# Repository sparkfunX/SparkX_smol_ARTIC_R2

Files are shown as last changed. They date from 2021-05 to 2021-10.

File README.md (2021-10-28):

# SparkX smôl ARTIC R2

SparkX smôl ARTIC R2 (SPX-18618) (https://www.sparkfun.com/products/18618)

[*SparkX smôl ARTIC R2 (SPX-18618)*](https://www.sparkfun.com/products/18618)

The ARGOS ARTIC R2 satellite communication chipset in smôl format.

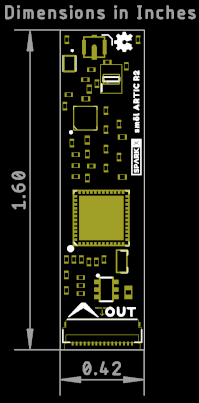
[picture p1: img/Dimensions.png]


## Repository Contents

- [**/Hardware**](./Hardware) - Eagle PCB, SCH and LBR design files
- [**LICENSE.md**](./LICENSE.md) - contains the licence information

## Product Versions

- [SPX-18618](https://www.sparkfun.com/products/18618) - Original SparkX Release.

## Thanks

The ARTIC R2 circuit is a remix of the reference design kindly provided by the [Arribada Initiative](https://arribada.org/) and Icoteq Ltd.

## License Information

This product is _**open source**_!

Please review the LICENSE.md file for license information.

If you have any questions or concerns on licensing, please contact technical support on our [SparkFun forums](https://forum.sparkfun.com/viewforum.php?f=123).

Distributed as-is; no warranty is given.

- Your friends at SparkFun.

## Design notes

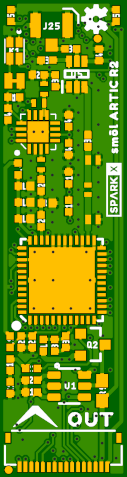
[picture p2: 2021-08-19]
img/Top.png

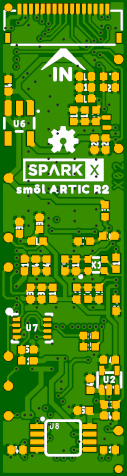
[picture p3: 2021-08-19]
img/Bottom.png

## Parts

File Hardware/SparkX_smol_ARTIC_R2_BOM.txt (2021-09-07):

Partlist exported from C:/Users/pc235/Documents/EAGLE/SparkX_smol_ARTIC_R2/X02/SparkX_smol_ARTIC_R2.sch at 07/09/2021 13:14

Part      Value                         Device                          Package                       Description                                                                                                     DESCRIPTION                                               DESIGNER DIGIKEY_PART                             MANUFACTURER_NAME MANUFACTURER_PART_NUMBER MANU_PART                MOUSER_PART          MOUSER_PART_NUMBER PACKAGE   PROD_ID     REV VALUE        
1V8       TEST-POINT3                   TEST-POINT3                     PAD.03X.03                    SparkFun Test Points                                                                                                                                                                                                                                                                                                                                                           
3V0       TEST-POINT3                   TEST-POINT3                     PAD.03X.03                    SparkFun Test Points                                                                                                                                                                                                                                                                                                                                                           
C1        2.2uF                         2.2UF-0402_TIGHT-10V-10%-X5R    0402-TIGHT                    2.2µF ceramic capacitors                                                                                                                                                                                                                                                                                                                          CAP-14232       2.2uF        
C2        10nF                          10NF-0402T-25V-10%              0402-TIGHT                    0.01uF/10nF/10,000pF ceramic capacitors                                                                                                                                                                                                                                                                                                           CAP-14847       10nF         
C3        1.0uF                         1.0UF-0402T-16V-10%             0402-TIGHT                    1µF ceramic capacitors                                                                                                                                                                                                                                                                                                                            CAP-12417       1.0uF        
C4        1.0uF                         1.0UF-0402T-16V-10%             0402-TIGHT                    1µF ceramic capacitors                                                                                                                                                                                                                                                                                                                            CAP-12417       1.0uF        
C5        22pF                          22PF-0402T-16V-10%              0402-TIGHT                    22pF ceramic capacitors                                                                                                                                                                                                                                                                                                                           CAP-14674       22pF         
C6        0.1uF                         0.1UF-0402T-6.3V-10%-X7R        0402-TIGHT                    0.1µF ceramic capacitors                                                                                                                                                                                                                                                                                                                          CAP-14993       0.1uF        
C7        22pF                          22PF-0402T-16V-10%              0402-TIGHT                    22pF ceramic capacitors                                                                                                                                                                                                                                                                                                                           CAP-14674       22pF         
C8        0.1uF                         0.1UF-0402T-6.3V-10%-X7R        0402-TIGHT                    0.1µF ceramic capacitors                                                                                                                                                                                                                                                                                                                          CAP-14993       0.1uF        
C9        1.0uF                         1.0UF-0402T-16V-10%             0402-TIGHT                    1µF ceramic capacitors                                                                                                                                                                                                                                                                                                                            CAP-12417       1.0uF        
C10       47nF                          47NF-0402_TIGHT-25V-10%-X7R     0402-TIGHT                    47nF ceramic capacitors                                                                                                                                                                                                                                                                                                                           CAP-14243       47nF         
C11       100pF                         100PF-0402T-50V-5%              0402-TIGHT                    100pF/0.1nF ceramic capacitors                                                                                                                                                                                                                                                                                                                    CAP-13458       100pF        
C12       1.0uF                         1.0UF-0402T-16V-10%             0402-TIGHT                    1µF ceramic capacitors                                                                                                                                                                                                                                                                                                                            CAP-12417       1.0uF        
C13       10uF                          10UF-0402T-6.3V-20%             0402-TIGHT                    10.0µF ceramic capacitors                                                                                                                                                                                                                                                                                                                         CAP-14848       10uF         
C14       10uF                          10UF-0402T-6.3V-20%             0402-TIGHT                    10.0µF ceramic capacitors                                                                                                                                                                                                                                                                                                                         CAP-14848       10uF         
C15       2.2uF                         2.2UF-0402_TIGHT-10V-10%-X5R    0402-TIGHT                    2.2µF ceramic capacitors                                                                                                                                                                                                                                                                                                                          CAP-14232       2.2uF        
C16       2.2uF                         2.2UF-0402_TIGHT-10V-10%-X5R    0402-TIGHT                    2.2µF ceramic capacitors                                                                                                                                                                                                                                                                                                                          CAP-14232       2.2uF        
C17       1.0nF                         1.0NF/1000PF-0402_TIGHT-50V-10% 0402-TIGHT                    1nF/1,000pF ceramic capacitors                                                                                                                                                                                                                                                                                                                    CAP-14280       1.0nF        
C18       22pF                          22PF-0402T-16V-10%              0402-TIGHT                    22pF ceramic capacitors                                                                                                                                                                                                                                                                                                                           CAP-14674       22pF         
C19       100pF                         100PF-0402T-50V-5%              0402-TIGHT                    100pF/0.1nF ceramic capacitors                                                                                                                                                                                                                                                                                                                    CAP-13458       100pF        
C20       2.2uF                         2.2UF-0402_TIGHT-10V-10%-X5R    0402-TIGHT                    2.2µF ceramic capacitors                                                                                                                                                                                                                                                                                                                          CAP-14232       2.2uF        
C21       100pF                         100PF-0402T-50V-5%              0402-TIGHT                    100pF/0.1nF ceramic capacitors                                                                                                                                                                                                                                                                                                                    CAP-13458       100pF        
C22       100pF                         100PF-0402T-50V-5%              0402-TIGHT                    100pF/0.1nF ceramic capacitors                                                                                                                                                                                                                                                                                                                    CAP-13458       100pF        
C23       1.0uF                         1.0UF-0402T-16V-10%             0402-TIGHT                    1µF ceramic capacitors                                                                                                                                                                                                                                                                                                                            CAP-12417       1.0uF        
C24       100pF                         100PF-0402T-50V-5%              0402-TIGHT                    100pF/0.1nF ceramic capacitors                                                                                                                                                                                                                                                                                                                    CAP-13458       100pF        
C25       100pF                         100PF-0402T-50V-5%              0402-TIGHT                    100pF/0.1nF ceramic capacitors                                                                                                                                                                                                                                                                                                                    CAP-13458       100pF        
C26       0.1uF                         0.1UF-0402T-6.3V-10%-X7R        0402-TIGHT                    0.1µF ceramic capacitors                                                                                                                                                                                                                                                                                                                          CAP-14993       0.1uF        
C27       22pF                          22PF-0402T-16V-10%              0402-TIGHT                    22pF ceramic capacitors                                                                                                                                                                                                                                                                                                                           CAP-14674       22pF         
C28       9.1pF                         9.1PF-0402-TIGHT                0402-TIGHT                    9.1pF ceramic capacitors                                                                                                                                                                                                                                                                        609-500R07S9R1CV4T                                CAP-15278       9.1pF        
C29       2.4 pF                        2.4PF-0402                      0402_MURATA                                                                                                                                                                                                                                                                                                                                                                     CAP-14351       2.4 pF       
C30       100pF                         100PF-0402T-50V-5%              0402-TIGHT                    100pF/0.1nF ceramic capacitors                                                                                                                                                                                                                                                                                                                    CAP-13458       100pF        
C31       100pF                         100PF-0402T-50V-5%              0402-TIGHT                    100pF/0.1nF ceramic capacitors                                                                                                                                                                                                                                                                                                                    CAP-13458       100pF        
C32       0.1uF                         0.1UF-0402T-6.3V-10%-X7R        0402-TIGHT                    0.1µF ceramic capacitors                                                                                                                                                                                                                                                                                                                          CAP-14993       0.1uF        
C33       22pF                          22PF-0402T-16V-10%              0402-TIGHT                    22pF ceramic capacitors                                                                                                                                                                                                                                                                                                                           CAP-14674       22pF         
C34       22pF                          22PF-0402T-16V-10%              0402-TIGHT                    22pF ceramic capacitors                                                                                                                                                                                                                                                                                                                           CAP-14674       22pF         
C35       0.1uF                         0.1UF-0402T-6.3V-10%-X7R        0402-TIGHT                    0.1µF ceramic capacitors                                                                                                                                                                                                                                                                                                                          CAP-14993       0.1uF        
C36       100pF                         100PF-0402T-50V-5%              0402-TIGHT                    100pF/0.1nF ceramic capacitors                                                                                                                                                                                                                                                                                                                    CAP-13458       100pF        
C37       100pF                         100PF-0402T-50V-5%              0402-TIGHT                    100pF/0.1nF ceramic capacitors                                                                                                                                                                                                                                                                                                                    CAP-13458       100pF        
C38       0.1uF                         0.1UF-0402T-6.3V-10%-X7R        0402-TIGHT                    0.1µF ceramic capacitors                                                                                                                                                                                                                                                                                                                          CAP-14993       0.1uF        
C39       22pF                          22PF-0402T-16V-10%              0402-TIGHT                    22pF ceramic capacitors                                                                                                                                                                                                                                                                                                                           CAP-14674       22pF         
C40       22pF                          22PF-0402T-16V-10%              0402-TIGHT                    22pF ceramic capacitors                                                                                                                                                                                                                                                                                                                           CAP-14674       22pF         
C41       0.1uF                         0.1UF-0402T-6.3V-10%-X7R        0402-TIGHT                    0.1µF ceramic capacitors                                                                                                                                                                                                                                                                                                                          CAP-14993       0.1uF        
C42       100pF                         100PF-0402T-50V-5%              0402-TIGHT                    100pF/0.1nF ceramic capacitors                                                                                                                                                                                                                                                                                                                    CAP-13458       100pF        
C43       100pF                         100PF-0402T-50V-5%              0402-TIGHT                    100pF/0.1nF ceramic capacitors                                                                                                                                                                                                                                                                                                                    CAP-13458       100pF        
C44       2.2uF                         2.2UF-0402_TIGHT-10V-10%-X5R    0402-TIGHT                    2.2µF ceramic capacitors                                                                                                                                                                                                                                                                                                                          CAP-14232       2.2uF        
C45       2.2uF                         2.2UF-0402_TIGHT-10V-10%-X5R    0402-TIGHT                    2.2µF ceramic capacitors                                                                                                                                                                                                                                                                                                                          CAP-14232       2.2uF        
C46       1.0uF                         1.0UF-0402T-16V-10%             0402-TIGHT                    1µF ceramic capacitors                                                                                                                                                                                                                                                                                                                            CAP-12417       1.0uF        
C47       100pF                         100PF-0402T-50V-5%              0402-TIGHT                    100pF/0.1nF ceramic capacitors                                                                                                                                                                                                                                                                                                                    CAP-13458       100pF        
C48       2.2uF                         2.2UF-0402_TIGHT-10V-10%-X5R    0402-TIGHT                    2.2µF ceramic capacitors                                                                                                                                                                                                                                                                                                                          CAP-14232       2.2uF        
C49       0.1uF                         0.1UF-0402T-10V-10%-X7R         0402-TIGHT                    0.1µF ceramic capacitors                                                                                                                                                                                                                                                                                                                          CAP-15083       0.1uF        
C50       0.1uF                         0.1UF-0402T-6.3V-10%-X7R        0402-TIGHT                    0.1µF ceramic capacitors                                                                                                                                                                                                                                                                                                                          CAP-14993       0.1uF        
C51       0.1uF                         0.1UF-0402T-10V-10%-X7R         0402-TIGHT                    0.1µF ceramic capacitors                                                                                                                                                                                                                                                                                                                          CAP-15083       0.1uF        
C52       2.2uF                         2.2UF-0402_TIGHT-10V-10%-X5R    0402-TIGHT                    2.2µF ceramic capacitors                                                                                                                                                                                                                                                                                                                          CAP-14232       2.2uF        
C53       2.2uF                         2.2UF-0402_TIGHT-10V-10%-X5R    0402-TIGHT                    2.2µF ceramic capacitors                                                                                                                                                                                                                                                                                                                          CAP-14232       2.2uF        
CS0       TEST-POINT3                   TEST-POINT3                     PAD.03X.03                    SparkFun Test Points                                                                                                                                                                                                                                                                                                                                                           
FD1       FIDUCIALUFIDUCIAL             FIDUCIALUFIDUCIAL               FIDUCIAL-MICRO                Fiducial Alignment Points                                                                                                                                                                                                                                                                                                                                                      
FD2       FIDUCIALUFIDUCIAL             FIDUCIALUFIDUCIAL               FIDUCIAL-MICRO                Fiducial Alignment Points                                                                                                                                                                                                                                                                                                                                                      
FD3       FIDUCIALUFIDUCIAL             FIDUCIALUFIDUCIAL               FIDUCIAL-MICRO                Fiducial Alignment Points                                                                                                                                                                                                                                                                                                                                                      
FD4       FIDUCIALUFIDUCIAL             FIDUCIALUFIDUCIAL               FIDUCIAL-MICRO                Fiducial Alignment Points                                                                                                                                                                                                                                                                                                                                                      
FLSH_CEN  TEST-POINT3                   TEST-POINT3                     PAD.03X.03                    SparkFun Test Points                                                                                                                                                                                                                                                                                                                                                           
FLSH_SCLK TEST-POINT3                   TEST-POINT3                     PAD.03X.03                    SparkFun Test Points
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

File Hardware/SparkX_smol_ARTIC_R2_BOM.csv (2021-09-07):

Part | Value | Device | Package | Description | DESCRIPTION | DESIGNER | DIGIKEY_PART | MANUFACTURER_NAME | MANUFACTURER_PART_NUMBER | MANU_PART | MOUSER_PART | MOUSER_PART_NUMBER | PACKAGE | PROD_ID | REV | VALUE
1V8 | TEST-POINT3 | TEST-POINT3 | PAD.03X.03 | SparkFun Test Points
3V0 | TEST-POINT3 | TEST-POINT3 | PAD.03X.03 | SparkFun Test Points
C1 | 2.2uF | 2.2UF-0402_TIGHT-10V-10%-X5R | 0402-TIGHT | 2.2µF ceramic capacitors |  |  |  |  |  |  |  |  |  | CAP-14232 |  | 2.2uF
C2 | 10nF | 10NF-0402T-25V-10% | 0402-TIGHT | 0.01uF/10nF/10,000pF ceramic capacitors |  |  |  |  |  |  |  |  |  | CAP-14847 |  | 10nF
C3 | 1.0uF | 1.0UF-0402T-16V-10% | 0402-TIGHT | 1µF ceramic capacitors |  |  |  |  |  |  |  |  |  | CAP-12417 |  | 1.0uF
C4 | 1.0uF | 1.0UF-0402T-16V-10% | 0402-TIGHT | 1µF ceramic capacitors |  |  |  |  |  |  |  |  |  | CAP-12417 |  | 1.0uF
C5 | 22pF | 22PF-0402T-16V-10% | 0402-TIGHT | 22pF ceramic capacitors |  |  |  |  |  |  |  |  |  | CAP-14674 |  | 22pF
C6 | 0.1uF | 0.1UF-0402T-6.3V-10%-X7R | 0402-TIGHT | 0.1µF ceramic capacitors |  |  |  |  |  |  |  |  |  | CAP-14993 |  | 0.1uF
C7 | 22pF | 22PF-0402T-16V-10% | 0402-TIGHT | 22pF ceramic capacitors |  |  |  |  |  |  |  |  |  | CAP-14674 |  | 22pF
C8 | 0.1uF | 0.1UF-0402T-6.3V-10%-X7R | 0402-TIGHT | 0.1µF ceramic capacitors |  |  |  |  |  |  |  |  |  | CAP-14993 |  | 0.1uF
C9 | 1.0uF | 1.0UF-0402T-16V-10% | 0402-TIGHT | 1µF ceramic capacitors |  |  |  |  |  |  |  |  |  | CAP-12417 |  | 1.0uF
C10 | 47nF | 47NF-0402_TIGHT-25V-10%-X7R | 0402-TIGHT | 47nF ceramic capacitors |  |  |  |  |  |  |  |  |  | CAP-14243 |  | 47nF
C11 | 100pF | 100PF-0402T-50V-5% | 0402-TIGHT | 100pF/0.1nF ceramic capacitors |  |  |  |  |  |  |  |  |  | CAP-13458 |  | 100pF
C12 | 1.0uF | 1.0UF-0402T-16V-10% | 0402-TIGHT | 1µF ceramic capacitors |  |  |  |  |  |  |  |  |  | CAP-12417 |  | 1.0uF
C13 | 10uF | 10UF-0402T-6.3V-20% | 0402-TIGHT | 10.0µF ceramic capacitors |  |  |  |  |  |  |  |  |  | CAP-14848 |  | 10uF
C14 | 10uF | 10UF-0402T-6.3V-20% | 0402-TIGHT | 10.0µF ceramic capacitors |  |  |  |  |  |  |  |  |  | CAP-14848 |  | 10uF
C15 | 2.2uF | 2.2UF-0402_TIGHT-10V-10%-X5R | 0402-TIGHT | 2.2µF ceramic capacitors |  |  |  |  |  |  |  |  |  | CAP-14232 |  | 2.2uF
C16 | 2.2uF | 2.2UF-0402_TIGHT-10V-10%-X5R | 0402-TIGHT | 2.2µF ceramic capacitors |  |  |  |  |  |  |  |  |  | CAP-14232 |  | 2.2uF
C17 | 1.0nF | 1.0NF/1000PF-0402_TIGHT-50V-10% | 0402-TIGHT | 1nF/1,000pF ceramic capacitors |  |  |  |  |  |  |  |  |  | CAP-14280 |  | 1.0nF
C18 | 22pF | 22PF-0402T-16V-10% | 0402-TIGHT | 22pF ceramic capacitors |  |  |  |  |  |  |  |  |  | CAP-14674 |  | 22pF
C19 | 100pF | 100PF-0402T-50V-5% | 0402-TIGHT | 100pF/0.1nF ceramic capacitors |  |  |  |  |  |  |  |  |  | CAP-13458 |  | 100pF
C20 | 2.2uF | 2.2UF-0402_TIGHT-10V-10%-X5R | 0402-TIGHT | 2.2µF ceramic capacitors |  |  |  |  |  |  |  |  |  | CAP-14232 |  | 2.2uF
C21 | 100pF | 100PF-0402T-50V-5% | 0402-TIGHT | 100pF/0.1nF ceramic capacitors |  |  |  |  |  |  |  |  |  | CAP-13458 |  | 100pF
C22 | 100pF | 100PF-0402T-50V-5% | 0402-TIGHT | 100pF/0.1nF ceramic capacitors |  |  |  |  |  |  |  |  |  | CAP-13458 |  | 100pF
C23 | 1.0uF | 1.0UF-0402T-16V-10% | 0402-TIGHT | 1µF ceramic capacitors |  |  |  |  |  |  |  |  |  | CAP-12417 |  | 1.0uF
C24 | 100pF | 100PF-0402T-50V-5% | 0402-TIGHT | 100pF/0.1nF ceramic capacitors |  |  |  |  |  |  |  |  |  | CAP-13458 |  | 100pF
C25 | 100pF | 100PF-0402T-50V-5% | 0402-TIGHT | 100pF/0.1nF ceramic capacitors |  |  |  |  |  |  |  |  |  | CAP-13458 |  | 100pF
C26 | 0.1uF | 0.1UF-0402T-6.3V-10%-X7R | 0402-TIGHT | 0.1µF ceramic capacitors |  |  |  |  |  |  |  |  |  | CAP-14993 |  | 0.1uF
C27 | 22pF | 22PF-0402T-16V-10% | 0402-TIGHT | 22pF ceramic capacitors |  |  |  |  |  |  |  |  |  | CAP-14674 |  | 22pF
C28 | 9.1pF | 9.1PF-0402-TIGHT | 0402-TIGHT | 9.1pF ceramic capacitors |  |  |  |  |  |  | 609-500R07S9R1CV4T |  |  | CAP-15278 |  | 9.1pF
C29 | 2.4 pF | 2.4PF-0402 | 0402_MURATA |  |  |  |  |  |  |  |  |  |  | CAP-14351 |  | 2.4 pF
C30 | 100pF | 100PF-0402T-50V-5% | 0402-TIGHT | 100pF/0.1nF ceramic capacitors |  |  |  |  |  |  |  |  |  | CAP-13458 |  | 100pF
C31 | 100pF | 100PF-0402T-50V-5% | 0402-TIGHT | 100pF/0.1nF ceramic capacitors |  |  |  |  |  |  |  |  |  | CAP-13458 |  | 100pF
C32 | 0.1uF | 0.1UF-0402T-6.3V-10%-X7R | 0402-TIGHT | 0.1µF ceramic capacitors |  |  |  |  |  |  |  |  |  | CAP-14993 |  | 0.1uF
C33 | 22pF | 22PF-0402T-16V-10% | 0402-TIGHT | 22pF ceramic capacitors |  |  |  |  |  |  |  |  |  | CAP-14674 |  | 22pF
C34 | 22pF | 22PF-0402T-16V-10% | 0402-TIGHT | 22pF ceramic capacitors |  |  |  |  |  |  |  |  |  | CAP-14674 |  | 22pF
C35 | 0.1uF | 0.1UF-0402T-6.3V-10%-X7R | 0402-TIGHT | 0.1µF ceramic capacitors |  |  |  |  |  |  |  |  |  | CAP-14993 |  | 0.1uF
C36 | 100pF | 100PF-0402T-50V-5% | 0402-TIGHT | 100pF/0.1nF ceramic capacitors |  |  |  |  |  |  |  |  |  | CAP-13458 |  | 100pF
C37 | 100pF | 100PF-0402T-50V-5% | 0402-TIGHT | 100pF/0.1nF ceramic capacitors |  |  |  |  |  |  |  |  |  | CAP-13458 |  | 100pF
C38 | 0.1uF | 0.1UF-0402T-6.3V-10%-X7R | 0402-TIGHT | 0.1µF ceramic capacitors |  |  |  |  |  |  |  |  |  | CAP-14993 |  | 0.1uF
C39 | 22pF | 22PF-0402T-16V-10% | 0402-TIGHT | 22pF ceramic capacitors |  |  |  |  |  |  |  |  |  | CAP-14674 |  | 22pF
C40 | 22pF | 22PF-0402T-16V-10% | 0402-TIGHT | 22pF ceramic capacitors |  |  |  |  |  |  |  |  |  | CAP-14674 |  | 22pF
C41 | 0.1uF | 0.1UF-0402T-6.3V-10%-X7R | 0402-TIGHT | 0.1µF ceramic capacitors |  |  |  |  |  |  |  |  |  | CAP-14993 |  | 0.1uF
C42 | 100pF | 100PF-0402T-50V-5% | 0402-TIGHT | 100pF/0.1nF ceramic capacitors |  |  |  |  |  |  |  |  |  | CAP-13458 |  | 100pF
C43 | 100pF | 100PF-0402T-50V-5% | 0402-TIGHT | 100pF/0.1nF ceramic capacitors |  |  |  |  |  |  |  |  |  | CAP-13458 |  | 100pF
C44 | 2.2uF | 2.2UF-0402_TIGHT-10V-10%-X5R | 0402-TIGHT | 2.2µF ceramic capacitors |  |  |  |  |  |  |  |  |  | CAP-14232 |  | 2.2uF
C45 | 2.2uF | 2.2UF-0402_TIGHT-10V-10%-X5R | 0402-TIGHT | 2.2µF ceramic capacitors |  |  |  |  |  |  |  |  |  | CAP-14232 |  | 2.2uF
C46 | 1.0uF | 1.0UF-0402T-16V-10% | 0402-TIGHT | 1µF ceramic capacitors |  |  |  |  |  |  |  |  |  | CAP-12417 |  | 1.0uF
C47 | 100pF | 100PF-0402T-50V-5% | 0402-TIGHT | 100pF/0.1nF ceramic capacitors |  |  |  |  |  |  |  |  |  | CAP-13458 |  | 100pF
C48 | 2.2uF | 2.2UF-0402_TIGHT-10V-10%-X5R | 0402-TIGHT | 2.2µF ceramic capacitors |  |  |  |  |  |  |  |  |  | CAP-14232 |  | 2.2uF
C49 | 0.1uF | 0.1UF-0402T-10V-10%-X7R | 0402-TIGHT | 0.1µF ceramic capacitors |  |  |  |  |  |  |  |  |  | CAP-15083 |  | 0.1uF
C50 | 0.1uF | 0.1UF-0402T-6.3V-10%-X7R | 0402-TIGHT | 0.1µF ceramic capacitors |  |  |  |  |  |  |  |  |  | CAP-14993 |  | 0.1uF
C51 | 0.1uF | 0.1UF-0402T-10V-10%-X7R | 0402-TIGHT | 0.1µF ceramic capacitors |  |  |  |  |  |  |  |  |  | CAP-15083 |  | 0.1uF
C52 | 2.2uF | 2.2UF-0402_TIGHT-10V-10%-X5R | 0402-TIGHT | 2.2µF ceramic capacitors |  |  |  |  |  |  |  |  |  | CAP-14232 |  | 2.2uF
C53 | 2.2uF | 2.2UF-0402_TIGHT-10V-10%-X5R | 0402-TIGHT | 2.2µF ceramic capacitors |  |  |  |  |  |  |  |  |  | CAP-14232 |  | 2.2uF
CS0 | TEST-POINT3 | TEST-POINT3 | PAD.03X.03 | SparkFun Test Points
FD1 | FIDUCIALUFIDUCIAL | FIDUCIALUFIDUCIAL | FIDUCIAL-MICRO | Fiducial Alignment Points
FD2 | FIDUCIALUFIDUCIAL | FIDUCIALUFIDUCIAL | FIDUCIAL-MICRO | Fiducial Alignment Points
FD3 | FIDUCIALUFIDUCIAL | FIDUCIALUFIDUCIAL | FIDUCIAL-MICRO | Fiducial Alignment Points
FD4 | FIDUCIALUFIDUCIAL | FIDUCIALUFIDUCIAL | FIDUCIAL-MICRO | Fiducial Alignment Points
FLSH_CEN | TEST-POINT3 | TEST-POINT3 | PAD.03X.03 | SparkFun Test Points
FLSH_SCLK | TEST-POINT3 | TEST-POINT3 | PAD.03X.03 | SparkFun Test Points
FLSH_SI | TEST-POINT3 | TEST-POINT3 | PAD.03X.03 | SparkFun Test Points
FLSH_SO | TEST-POINT3 | TEST-POINT3 | PAD.03X.03 | SparkFun Test Points
FRAME1 | FRAME-LEDGER | FRAME-LEDGER | CREATIVE_COMMONS | Schematic Frame - Ledger
G16 | JUMPER-SMT_2_NC_TRACE_NO-SILK | JUMPER-SMT_2_NC_TRACE_NO-SILK | SMT-JUMPER_2_NC_TRACE_NO-SILK | Normally closed trace jumper
GPIO0 | TEST-POINT3 | TEST-POINT3 | PAD.03X.03 | SparkFun Test Points
IN |  | CONN_16FPC_16_0.5MM | FPC_16_0.5MM | Multi connection point. Often used as Generic Header-pin footprint for 0.1 inch spaced/style header connections |  |  |  |  |  |  |  |  |  | CONN-16066
J25 | U.FL | U.FL2PIN-REDUCED-FOOTPRINT | U.FL_REDUCED_FOOTPRINT | SMD Antenna Connector - U.FL |  |  |  |  |  |  |  |  |  | CONN-09193
K1 | TLP3475SRHA | TLP3475SRHA | TLP3475SRHA | Solid State Relays - PCB Mount Photo-IC 400mA 60V 500Vrms | Solid State Relays - PCB Mount Photo-IC 400mA 60V 500Vrms |  | 264-TLP3475SRHA(TPECT-ND - Cut Tape (CT) | Toshiba | TLP3475SRHA |  |  |  |  | IC-16019
L1 | 30Ω | FERRITE_BEAD-0402-30OHM-100MHZ | 0402-TIGHT | Ferrite Bead (blocks, cores, rings, chokes, etc.) |  |  |  |  |  |  |  |  |  | NDUC-15133 |  | 30Ω
L2 | 30Ω | FERRITE_BEAD-0402-30OHM-100MHZ | 0402-TIGHT | Ferrite Bead (blocks, cores, rings, chokes, etc.) |  |  |  |  |  |  |  |  |  | NDUC-15133 |  | 30Ω
L3 | 30Ω | FERRITE_BEAD-0402-30OHM-100MHZ | 0402-TIGHT | Ferrite Bead (blocks, cores, rings, chokes, etc.) |  |  |  |  |  |  |  |  |  | NDUC-15133 |  | 30Ω
L4 | 30Ω | FERRITE_BEAD-0402-30OHM-100MHZ | 0402-TIGHT | Ferrite Bead (blocks, cores, rings, chokes, etc.) |  |  |  |  |  |  |  |  |  | NDUC-15133 |  | 30Ω
L5 | 15nH | 15NH-0402 | 0402_COILCRAFT |  |  |  |  |  |  |  | 994-0402HP-15NXGLU |  |  | NDUC-15272 |  | 15nH
L6 | 27nH | 27NH-0402 | 0402_COILCRAFT |  |  |  |  |  |  |  | 994-0402HP-27NXGLU |  |  | NDUC-15273 |  | 27nH
L7 | 18nH | 18NH-0402 | 0402_COILCRAFT |  |  |  |  |  |  |  | 994-0402HP-18NXGLU |  |  | NDUC-15277 |  | 18nH
L8 | 12nH | 12NH-0402 | 0402_COILCRAFT |  |  |  |  |  |  |  | 994-0402HP-12NXGLU |  |  | NDUC-15271 |  | 12nH
L9 | 30Ω | FERRITE_BEAD-0402-30OHM-100MHZ | 0402-TIGHT | Ferrite Bead (blocks, cores, rings, chokes, etc.) |  |  |  |  |  |  |  |  |  | NDUC-15133 |  | 30Ω
L10 | 30Ω | FERRITE_BEAD-0402-30OHM-100MHZ | 0402-TIGHT | Ferrite Bead (blocks, cores, rings, chokes, etc.) |  |  |  |  |  |  |  |  |  | NDUC-15133 |  | 30Ω
L11 | 30nH | 30NH-0402 | 0402_COILCRAFT |  |  |  |  |  |  |  | 994-0402HP-30NXGLU |  |  | NDUC-15275 |  | 30nH
L12 | 51nH | 51NH-0402 | 0402_COILCRAFT |  |  |  |  |  |  |  | 994-0402HP-51NXGLU |  |  | NDUC-15276 |  | 51nH
L13 | 30Ω | FERRITE_BEAD-0402-30OHM-100MHZ | 0402-TIGHT | Ferrite Bead (blocks, cores, rings, chokes, etc.) |  |  |  |  |  |  |  |  |  | NDUC-15133 |  | 30Ω
L14 | 30Ω | FERRITE_BEAD-0402-30OHM-100MHZ | 0402-TIGHT | Ferrite Bead (blocks, cores, rings, chokes, etc.) |  |  |  |  |  |  |  |  |  | NDUC-15133 |  | 30Ω
L15 | 30Ω | FERRITE_BEAD-0402-30OHM-100MHZ | 0402-TIGHT | Ferrite Bead (blocks, cores, rings, chokes, etc.) |  |  |  |  |  |  |  |  |  | NDUC-15133 |  | 30Ω
LOGO1 | SPECIAL_INSTRUCTIONS-ORDERING | SPECIAL_INSTRUCTIONS-ORDERING | ORDERING_INSTRUCTIONS | Special Ordering/Production Instructions Alert
LOGO2 | OSHW-LOGOMINI | OSHW-LOGOMINI | OSHW-LOGO-MINI | Open-Source Hardware (OSHW) Logo
LOGO3 | OSHW-LOGOMINI | OSHW-LOGOMINI | OSHW-LOGO-MINI | Open-Source Hardware (OSHW) Logo
OUT |  | CONN_16FPC_16_0.5MM | FPC_16_0.5MM | Multi connection point. Often used as Generic Header-pin footprint for 0.1 inch spaced/style header connections |  |  |  |  |  |  |  |  |  | CONN-16066
Q2 | 5.8A/30V/35mΩ | MOSFET-NCH-AO3404A | SOT23-3 | N-channel MOSFETs |  |  |  |  |  |  |  |  |  | TRANS-12988 |  | 5.8A/30V/35mΩ
R1 | 10k | 10KOHM-0402T-1/16W-1% | 0402-TIGHT | 10kΩ resistor |  |  |  |  |  |  |  |  |  | RES-14241 |  | 10k
R2 | 100 | 100OHM-0402-TIGHT-1/16W-1% | 0402-TIGHT | 100Ω resistor |  |  |  |  |  |  |  |  |  | RES-14962 |  | 100
R3 | 3.9 | 3.9OHM-0402-TIGHT-1/16W-1% | 0402-TIGHT | 3.9Ω resistor |  |  |  |  |  |  |  |  |  | RES-15270 |  | 3.9
R4 | 33k | 33KOHM-0402T-1/16W-1% | 0402-TIGHT | 33kΩ resistor |  |  |  |  |  |  |  |  |  | RES-15128 |  | 33k
R5 | 100k | 100KOHM-0402T-1/16W-1% | 0402-TIGHT | 100kΩ resistor |  |  |  |  |  |  |  |  |  | RES-13495 |  | 100k
R6 | 220 | 220OHM-0402-TIGHT-1/16W-1% | 0402-TIGHT | 220Ω resistor |  |  |  |  |  |  |  |  |  | RES-15269 |  | 220
R7 | 10k | 10KOHM-0402T-1/16W-1% | 0402-TIGHT | 10kΩ resistor |  |  |  |  |  |  |  |  |  | RES-14241 |  | 10k
R8 | 100k | 100KOHM-0402T-1/16W-1% | 0402-TIGHT | 100kΩ resistor |  |  |  |  |  |  |  |  |  | RES-13495 |  | 100k
R9 | 0.1 | 0.1OHM-0603-1/3W-1% | 0603 | 0.1Ω resistor |  |  |  |  |  |  |  |  |  | RES-15715 |  | 0.1
R11 | 100 | 100OHM-0402-TIGHT-1/16W-1% | 0402-TIGHT | 100Ω resistor |  |  |  |  |  |  |  |  |  | RES-14962 |  | 100
R12 | 10k | 10KOHM-0402T-1/16W-1% | 0402-TIGHT | 10kΩ resistor |  |  |  |  |  |  |  |  |  | RES-14241 |  | 10k
R14 | 470 | 470OHM-0402-TIGHT-1/16W-1% | 0402-TIGHT | 470Ω resistor |  |  |  |  |  |  |  |  |  | RES-15584 |  | 470
R17 | 47 | 47OHM-0402-TIGHT-1/16W-1% | 0402-TIGHT | 47Ω resistor |  |  |  |  |  |  |  |  |  | RES-15585 |  | 47
U$2 | SMOL_LOGOSMALL | SMOL_LOGOSMALL | SMOL_SMALL
U$3 | SMOL_LOGOSMALL | SMOL_LOGOSMALL | SMOL_SMALL
U$4 | SPARKX-LOGO3 | SPARKX-LOGO3 | SPARKX-SMALL
U$8 | SPARKX-LOGO2 | SPARKX-LOGO2 | SPARKX-TINY
U1 | ADM4210_1TSOT6 | ADM4210_1TSOT6 | TSOT6 | Hot Swap Controller |  |  |  |  |  |  |  |  |  | IC-16020
U2 | 1.8V/100mA | V_REG_SP6214-1.8V | SC70 | Voltage Regulator - SP6214 |  |  |  |  |  |  |  |  |  | VREG-08428 |  | 1.8V/100mA
U3 | ARTIC_R2 | ARTIC_R2 | QFN-48 | AnSem ARTIC R2 Chipset |  |  |  |  |  |  |  |  |  | IC-15312
U4 | RFPA0133 | RFPA0133 | QFN50P300X300X86-17N | IC PROG PWR AMP 16-QFN |  |  |  | Qorvo | RFPA0133TR7 |  |  | 772-RFPA0133 |  | IC-15274
U5 | AS179-92LF | AS179-92LF | SOT65P220X100-6N | SKYWORKS SOLUTIONS - AS179-92LF - IC, SWITCH, RF, SPDT, 0.02-3.0GHZ |  |  |  |  |  |  |  |  |  | IC-15047
U6 | 3.0V | V_REG_LP5907SOT23-3.0V | SOT23-5 | LP5907 - 250mA Ultra-Low-Noise LDO Regulator w/ Enable |  |  | 296-40357-1-ND |  |  | LP5907MFX-3.0/NOPB | 595-LP5907MFX-3.0NPB |  | SOT-23(5) | VREG-15586 |  | 3.0V
U7 | SST25VF020BUSON | SST25VF020BUSON | USON_3X2MM | 2Mbit Serial Flash Memory |  |  | SST25VF020B-80-4I-Q3AE-TCT-ND |  |  | SST25VF020B-80-4I-Q3AE-T |  |  |  | IC-15716
U8 | PCA9536 | PCA9536 | MSOP8 | PCA9536 4-Bit I2C I/O Expander |  |  |  |  |  |  |  |  |  | IC-15034
VDD | TEST-POINT3 | TEST-POINT3 | PAD.03X.03 | SparkFun Test Points
X1 | CRYSTAL-TCXO-26MHZ | CRYSTAL-TCXO-26MHZ | CRYSTAL-TCXO-SMD-1.65X1.25 | 26MHz Crystal Oscillator |  |  |  |  |  |  | 449-LFTCXO073004CUTT |  |  | XTAL-15279

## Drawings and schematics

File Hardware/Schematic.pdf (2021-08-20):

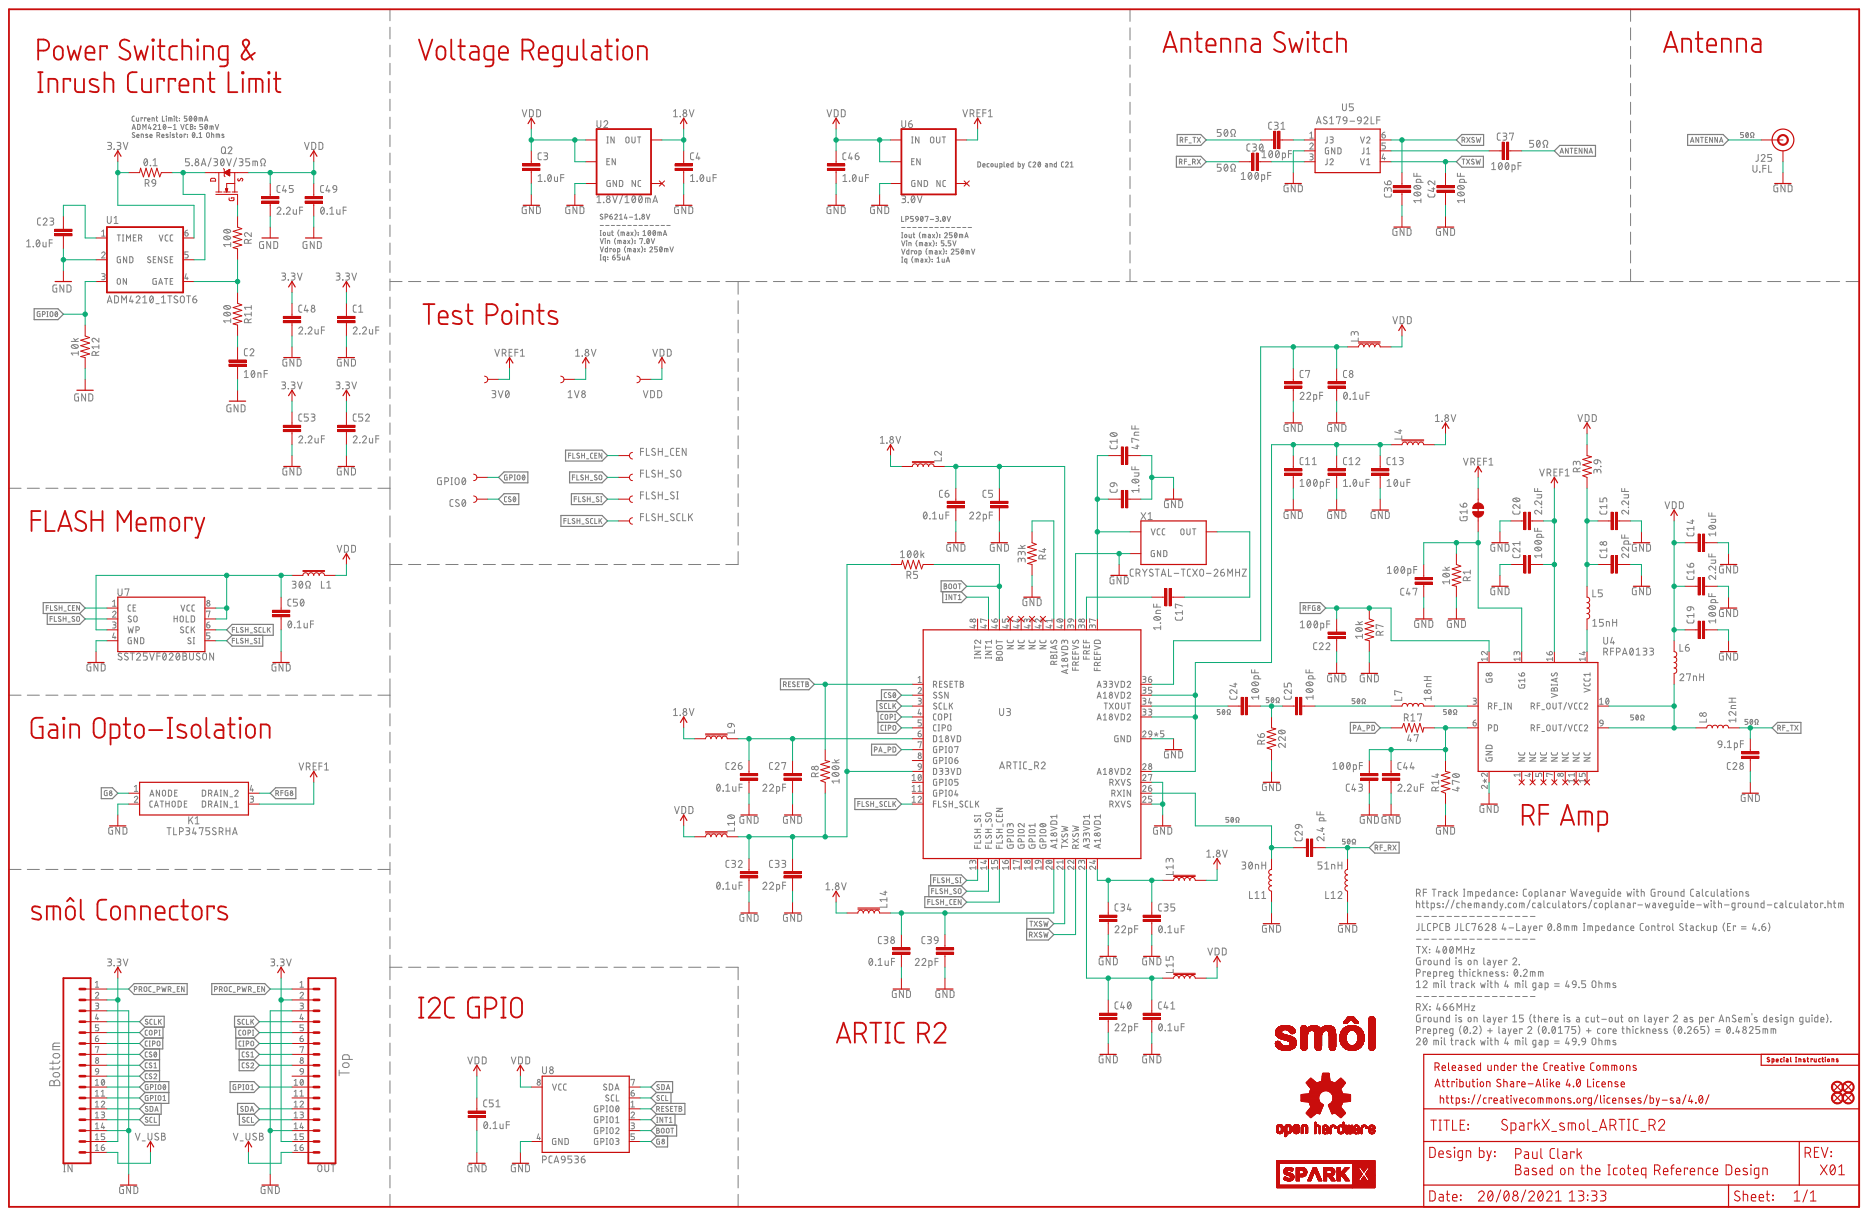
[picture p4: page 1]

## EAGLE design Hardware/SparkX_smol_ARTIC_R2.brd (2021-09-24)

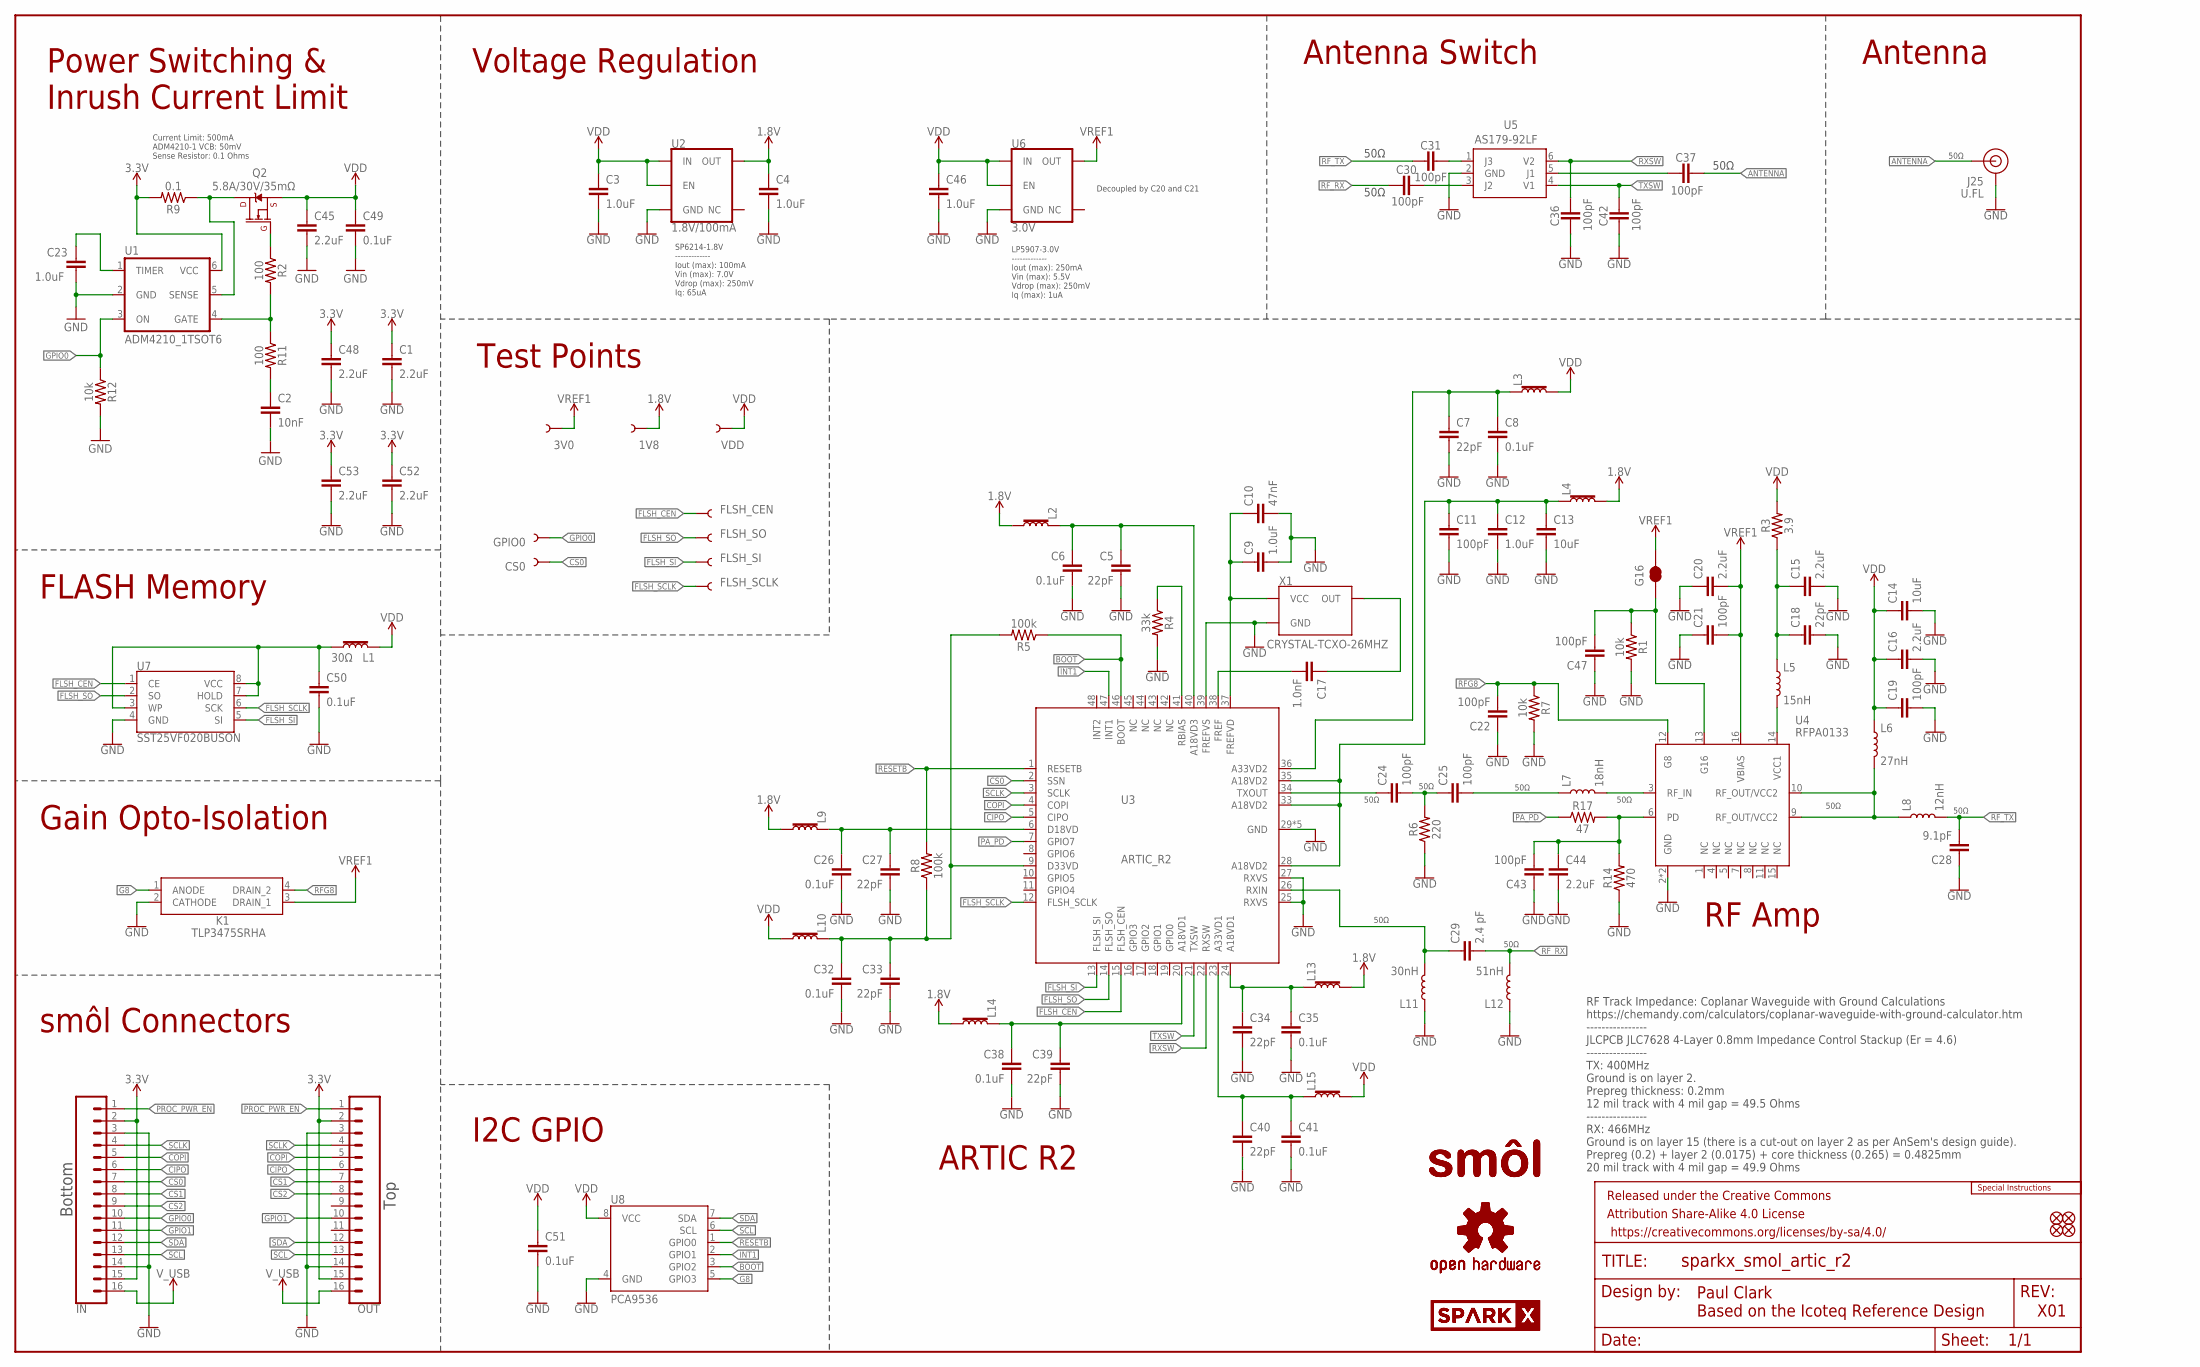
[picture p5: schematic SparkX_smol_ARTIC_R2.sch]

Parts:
1V8, 3V0: TEST-POINT3; PAD.03X.03
C1, C15, C16, C20, C44, C45, C48, C52, C53: 2.2uF; 0402-TIGHT
C2: 10nF; 0402-TIGHT
C3, C4, C9, C12, C23, C46: 1.0uF; 0402-TIGHT
C5, C7, C18, C27, C33, C34, C39, C40: 22pF; 0402-TIGHT
C6, C8, C26, C32, C35, C38, C41, C49, C50, C51: 0.1uF; 0402-TIGHT
C10: 47nF; 0402-TIGHT
C11, C19, C21, C22, C24, C25, C30, C31, C36, C37, C42, C43, C47: 100pF; 0402-TIGHT
C13, C14: 10uF; 0402-TIGHT
C17: 1.0nF; 0402-TIGHT
C28: 9.1pF; 0402-TIGHT
C29: 2.4 pF; 0402_MURATA
CS0: TEST-POINT3; PAD.03X.03
FD1, FD2, FD3, FD4: FIDUCIALUFIDUCIAL; FIDUCIAL-MICRO
FLSH_CEN: TEST-POINT3; PAD.03X.03
FLSH_SCLK: TEST-POINT3; PAD.03X.03
FLSH_SI: TEST-POINT3; PAD.03X.03
FLSH_SO: TEST-POINT3; PAD.03X.03
FRAME1: FRAME-LEDGER; CREATIVE_COMMONS
G16: JUMPER-SMT_2_NC_TRACE_NO-SILK; SMT-JUMPER_2_NC_TRACE_NO-SILK
GPIO0: TEST-POINT3; PAD.03X.03
IN: CONN_16FPC_16_0.5MM; FPC_16_0.5MM
J25: U.FL; U.FL_REDUCED_FOOTPRINT
K1: TLP3475SRHA
L1, L2, L3, L4, L9, L10, L13, L14, L15: 30Ω; 0402-TIGHT
L5: 15nH; 0402_COILCRAFT
L6: 27nH; 0402_COILCRAFT
L7: 18nH; 0402_COILCRAFT
L8: 12nH; 0402_COILCRAFT
L11: 30nH; 0402_COILCRAFT
L12: 51nH; 0402_COILCRAFT
LOGO1: SPECIAL_INSTRUCTIONS-ORDERING; ORDERING_INSTRUCTIONS
LOGO2, LOGO3: OSHW-LOGOMINI; OSHW-LOGO-MINI
OUT: CONN_16FPC_16_0.5MM; FPC_16_0.5MM
Q2: 5.8A/30V/35mΩ; SOT23-3
R1, R7, R12: 10k; 0402-TIGHT
R2, R11: 100; 0402-TIGHT
R3: 3.9; 0402-TIGHT
R4: 33k; 0402-TIGHT
R5, R8: 100k; 0402-TIGHT
R6: 220; 0402-TIGHT
R9: 0.1; 0603
R14: 470; 0402-TIGHT
R17: 47; 0402-TIGHT
U1: ADM4210_1TSOT6; TSOT6
U2: 1.8V/100mA; SC70
U3: ARTIC_R2; QFN-48
U4: RFPA0133; QFN50P300X300X86-17N
U5: AS179-92LF; SOT65P220X100-6N
U6: 3.0V; SOT23-5
U7: SST25VF020BUSON; USON_3X2MM
U8: PCA9536; MSOP8
U$2, U$3: SMOL_LOGOSMALL; SMOL_SMALL
U$4: SPARKX-LOGO3; SPARKX-SMALL
U$8: SPARKX-LOGO2; SPARKX-TINY
VDD: TEST-POINT3; PAD.03X.03
X1: CRYSTAL-TCXO-26MHZ; CRYSTAL-TCXO-SMD-1.65X1.25

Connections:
1.8V: 1V8.1, C4.1, L2.2, L4.2, L9.2, L13.2, L14.2, U2.5 (OUT)
3.3V: C1.1, C48.1, C52.1, C53.1, IN.2, IN.15, OUT.2, OUT.15, R9.2, U1.6 (VCC)
ANTENNA: C37.1, J25.FEED (SIGNAL)
BOOT: R5.1, U3.46 (BOOT), U8.3 (GPIO2)
CIPO: IN.6, OUT.6, U3.5 (CIPO)
COPI: IN.5, OUT.5, U3.4 (COPI)
CS0: CS0.1, IN.7, U3.2 (SSN)
CS1: IN.8, OUT.7
CS2: IN.9, OUT.8
FLASH_VCC: C50.1, L1.1, U7.3 (WP), U7.7 (HOLD), U7.8 (VCC)
FLSH_CEN: FLSH_CEN.1, U3.15 (FLSH_CEN), U7.1 (CE)
FLSH_SCLK: FLSH_SCLK.1, U3.12 (FLSH_SCLK), U7.6 (SCK)
FLSH_SI: FLSH_SI.1, U3.13 (FLSH_SI), U7.5 (SI)
FLSH_SO: FLSH_SO.1, U3.14 (FLSH_SO), U7.2 (SO)
G8: K1.1 (ANODE), U8.5 (GPIO3)
GND: C1.2, C2.2, C3.2, C4.2, C5.2, C6.2, C7.2, C8.2, C9.2, C10.2, C11.2, C12.2, C13.2, C14.2, C15.2, C16.2, C18.2, C19.2, C20.1, C21.1, C22.1, C23.2, C26.2, C27.2, C28.1, C32.2, C33.2, C34.2, C35.2, C36.2, C38.2, C39.2, C40.2, C41.2, C42.2, C43.1, C44.2, C45.2, C46.2, C47.1, C48.2, C49.2, C50.2, C51.2, C52.2, C53.2, IN.3, IN.14, J25.1 (GND), J25.2 (GND), K1.2 (CATHODE), L11.P$1 (1), L12.P$1 (1), OUT.3, OUT.14, R1.2, R4.2, R6.1, R7.2, R12.2, R14.1, U1.2 (GND), U2.2 (GND), U3.25 (RXVS), U3.27 (RXVS), U3.29 (GND), U3.30 (GND), U3.31 (GND), U3.32 (GND), U3.39 (FREFVS), U3.GND, U4.2 (GND), U4.EDAP (GND), U5.2 (GND), U6.2 (GND), U7.4 (GND), U8.4 (GND), X1.1 (GND), X1.2 (GND)
GPIO0: GPIO0.1, IN.10, R12.1, U1.3 (ON)
GPIO1: IN.11, OUT.10
INT1: U3.47 (INT1), U8.2 (GPIO1)
unnamed: Q2.3 (D), R9.1, U1.5 (SENSE)
unnamed: Q2.1 (G), R2.1
unnamed: R2.2, R11.1, U1.4 (GATE)
unnamed: C34.1, C35.1, L13.1, U3.24 (A18VD1)
unnamed: C40.1, C41.1, L15.1, U3.23 (A33VD1)
unnamed: C2.1, R11.2
unnamed: C23.1, U1.1 (TIMER)
unnamed: C26.1, C27.1, L9.1, U3.6 (D18VD)
unnamed: C32.1, C33.1, L10.1, R5.2, R8.1, U3.9 (D33VD)
unnamed: C11.1, C12.1, C13.1, L4.1, U3.28 (A18VD2), U3.33 (A18VD2), U3.35 (A18VD2)
unnamed: C7.1, C8.1, L3.1, U3.36 (A33VD2)
unnamed: R4.1, U3.41 (RBIAS)
unnamed: C5.1, C6.1, L2.1, U3.40 (A18VD3)
unnamed: C9.1, C10.1, U3.37 (FREFVD), X1.4 (VCC)
unnamed: C17.1, X1.3 (OUT)
unnamed: C17.2, U3.38 (FREF)
unnamed: C24.1, U3.34 (TXOUT)
unnamed: C24.2, C25.1, R6.2
unnamed: L5.P$2 (2), U4.14 (VCC1)
unnamed: C15.1, C18.1, L5.P$1 (1), R3.1
unnamed: C29.P$1 (1), L11.P$2 (2), U3.26 (RXIN)
unnamed: C25.2, L7.P$1 (1)
unnamed: L7.P$2 (2), U4.3 (RF_IN)
unnamed: L6.P$2 (2), L8.P$1 (1), U4.9 (RF_OUT/VCC2), U4.10 (RF_OUT/VCC2)
unnamed: C31.1, U5.1 (J3)
unnamed: C30.1, U5.3 (J2)
unnamed: C37.2, U5.5 (J1)
unnamed: C38.1, C39.1, L14.1, U3.20 (A18VD1)
PA_PD: R17.1, U3.7 (GPIO7)
PD: C43.2, C44.1, R14.2, R17.2, U4.6 (PD)
PROC_PWR_EN: IN.1, OUT.1
RESETB: R8.2, U3.1 (RESETB), U8.1 (GPIO0)
RFG8: C22.2, K1.4 (DRAIN_2), R7.1, U4.12 (G8)
RFG16: C47.2, G16.1, R1.1, U4.13 (G16)
RF_RX: C29.P$2 (2), C30.2, L12.P$2 (2)
RF_TX: C28.2, C31.2, L8.P$2 (2)
RXSW: C36.1, U3.22 (RXSW), U5.6 (V2)
SCL: IN.13, OUT.13, U8.6 (SCL)
SCLK: IN.4, OUT.4, U3.3 (SCLK)
SDA: IN.12, OUT.12, U8.7 (SDA)
TXSW: C42.1, U3.21 (TXSW), U5.4 (V1)
VDD: C3.1, C14.1, C16.1, C19.1, C45.1, C46.1, C49.1, C51.1, L1.2, L3.2, L6.P$1 (1), L10.2, L15.2, Q2.2 (S), R3.2, U2.1 (IN), U2.3 (EN), U6.1 (IN), U6.3 (EN), U8.8 (VCC), VDD.1
VREF1: 3V0.1, C20.2, C21.2, G16.2, K1.3 (DRAIN_1), U4.16 (VBIAS), U6.5 (OUT)
V_USB: IN.16, OUT.16

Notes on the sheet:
Paul Clark Based on the Icoteq Reference Design
X01
SP6214-1.8V ------------- Iout (max): 100mA Vin (max): 7.0V Vdrop (max): 250mV Iq: 65uA
Voltage Regulation
Antenna Switch
Antenna
ARTIC R2
RF Amp
Test Points
50Ω
RF Track Impedance: Coplanar Waveguide with Ground Calculations https://chemandy.com/calculators/coplanar-waveguide-with-ground-calculator.htm ---------------- JLCPCB JLC7628 4-Layer 0.8mm Impedance Control Stackup (Er = 4.6) ---------------- TX: 400MHz Ground is on layer 2. Prepreg thickness: 0.2m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
Gain Opto-Isolation
LP5907-3.0V ------------- Iout (max): 250mA Vin (max): 5.5V Vdrop (max): 250mV Iq (max): 1uA
Decoupled by C20 and C21
Power Switching & Inrush Current Limit
Current Limit: 500mA ADM4210-1 VCB: 50mV Sense Resistor: 0.1 Ohms
FLASH Memory
smôl Connectors
Bottom
Top
I2C GPIO

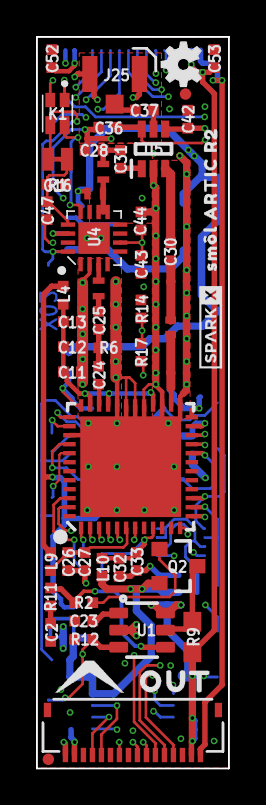
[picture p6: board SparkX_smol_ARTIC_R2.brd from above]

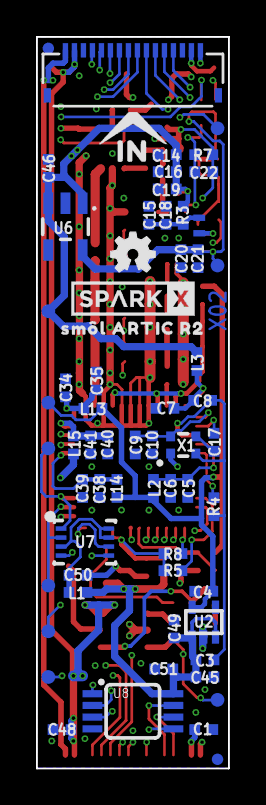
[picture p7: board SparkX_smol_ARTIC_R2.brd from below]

Board: 4 copper layers, 10.7 x 40.6 mm, 121 parts (64 on the bottom side), 63 nets.

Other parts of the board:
U$1: OUT0
U$7: IN0
U$9, U$10: SM�L_ARTIC_R20

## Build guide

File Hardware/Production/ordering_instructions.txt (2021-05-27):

JLCPCB JLC7628 4-Layer 0.8mm Impedance Control
panel size, 193x137mm
PCB thickness, 0.8mm
number of layers, 4
soldermask color, Black
silkscreen color, White
oz copper, 1oz
finish, ENIG
stencils, top+bottom
pcs per panel, 48
min trace width, 0.1270mm / 0.0050in
min drill size, 0.2000mm / 0.0079in
filename to layer stackup 1/2/3/4: GTL, GL2, GL3, GBL

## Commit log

2021-05-02 Ready for review
    [SparkX_EZ_ARTIC_R2.brd, SparkX_EZ_ARTIC_R2.sch]
2021-05-04 Review updates. Adding production files
    [SparkX_EZ_ARTIC_R2.brd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]
2021-05-27 Gapless production panel
    [SparkX_EZ_ARTIC_R2.brd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]
2021-06-09 Update 16-way FPC Connector
    [SparkX_EZ_ARTIC_R2.brd, SparkX_EZ_ARTIC_R2.sch]
2021-08-11 Fix glitch trapping in Example1. Improve power consumption in Example2.
2021-08-19 X02 - Add smôl branding
    [SparkX_EZ_ARTIC_R2.brd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]
2021-08-20 Change EZ to smôl on schematic
    [SparkX_smol_ARTIC_R2.sch]
2021-09-07 Add the BOM
    [SparkX_smol_ARTIC_R2_BOM.csv]
2021-09-24 Change ADM4210-1 from IC-16020 to IC-14694
    [SparkX_smol_ARTIC_R2.brd, SparkX_smol_ARTIC_R2.sch]

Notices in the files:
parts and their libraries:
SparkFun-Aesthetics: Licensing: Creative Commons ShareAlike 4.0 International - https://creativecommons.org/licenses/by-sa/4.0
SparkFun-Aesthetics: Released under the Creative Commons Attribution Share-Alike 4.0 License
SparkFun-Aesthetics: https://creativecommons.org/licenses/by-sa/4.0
